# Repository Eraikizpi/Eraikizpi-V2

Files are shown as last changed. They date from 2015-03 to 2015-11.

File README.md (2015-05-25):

# Eraikizpi-V2
Open source dlp/sla 3d printer

En Mayo de 2014, el laboratorio ciudadano Hirikilabs (http://hirikilabs.tabakalera.eu/) impulsado por Tabakalera junto a DSS2016 abre una nueva convocatoria de proyectos abiertos (http://hirikilabs.tabakalera.eu/blog/2014/05/26/convocatoria-de-proyectos-abiertos/) donde presentamos el proyecto de una impresora 3d dlp con nombre en clave Eraikizpi. Hirikilabs acepta y apadrina nuestro proyecto, ademas nos costea el prototipo y nos permite utilizar sus instalaciones y maquinaría para el propósito del proyecto. Desde ese momento empezamos a trabajar en Eraikizpi.

Eraikizpi v2 es una impresora 3d stereolitográfica (SLA) que utiliza una resina fotosensible que es curada gracias a la luz ultra violeta que emite un proyector dlp (Digital Light Processing).

Teneis mas información en reprap
http://reprap.org/wiki/Eraikizpi/es

La licencia de la impresora Eraikizpi es CC BY-NC 4.0 (http://creativecommons.org/licenses/by-nc/4.0/)

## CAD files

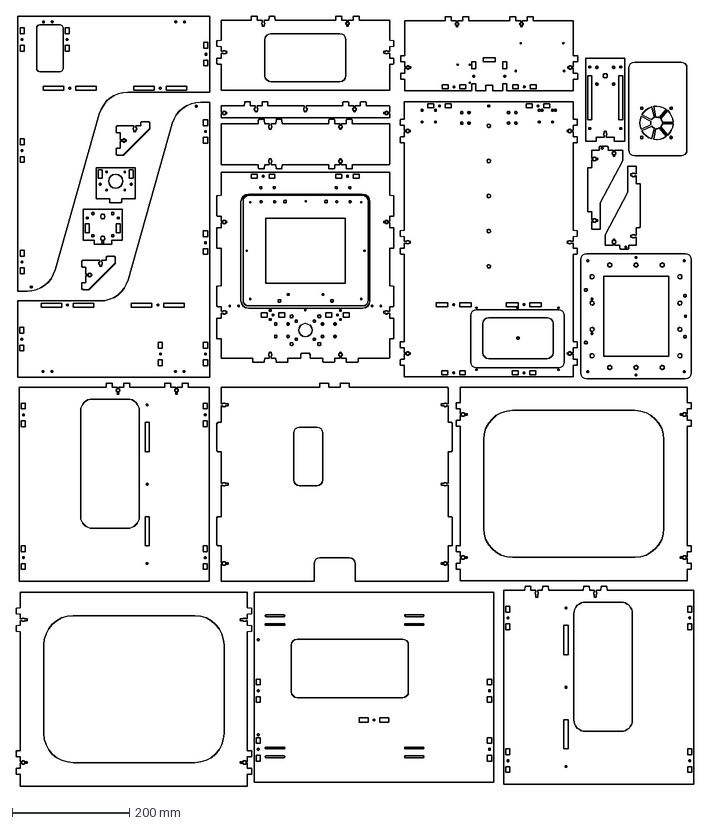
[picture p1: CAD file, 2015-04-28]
DXFs/DLP_V22_todo.DXF
1157.4 x 1315.2 mm

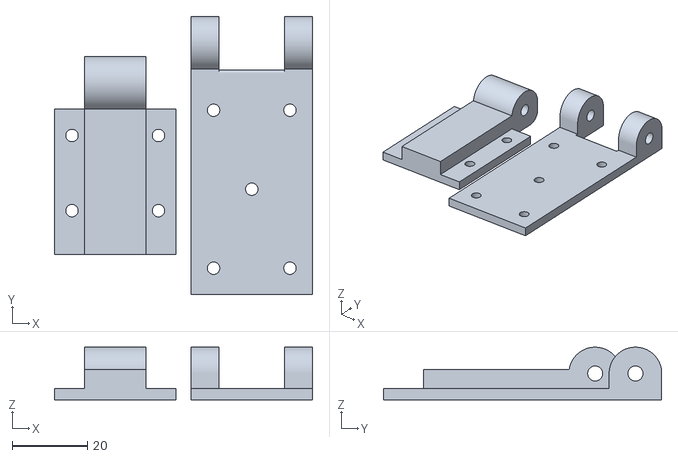
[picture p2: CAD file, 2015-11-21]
STLs/ERAKIZPI_V2_R2/ERKZP_V2_R2_02_bisagra_tapa_metacrilato.STL
68.6 x 73.9 x 14.0

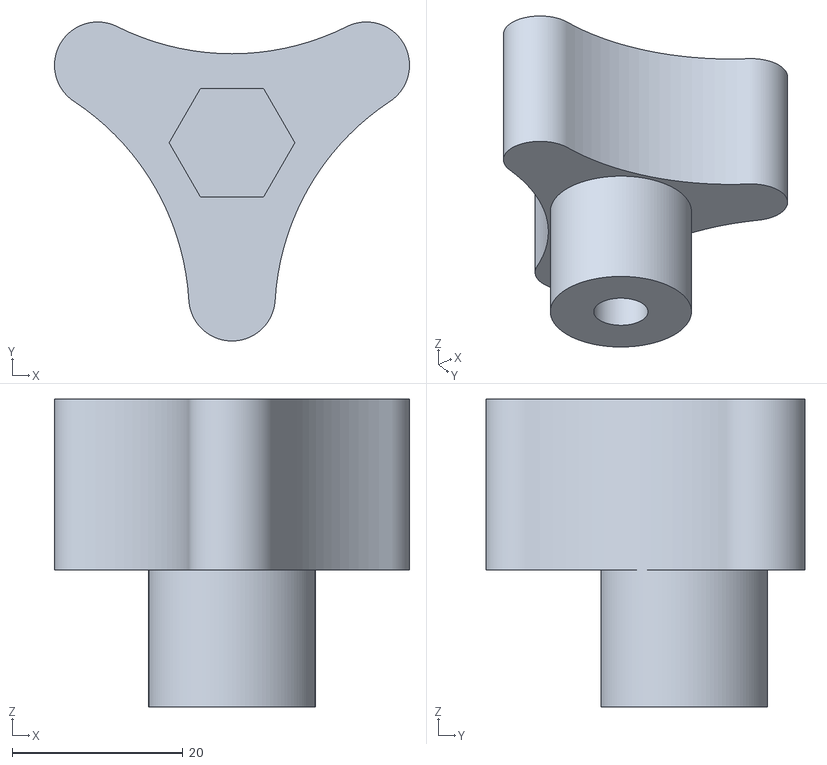
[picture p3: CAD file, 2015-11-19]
STLs/ERKZP_V2_R2_01_asa_bancada.STL
41.6 x 37.3 x 36.0

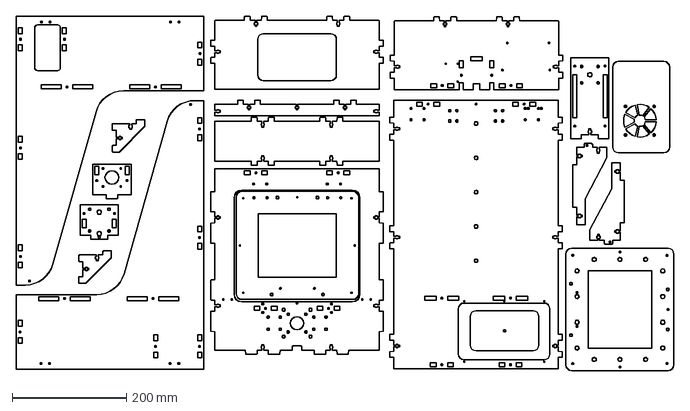
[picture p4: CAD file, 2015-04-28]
DXFs/DLP_V22_modulo_impresor.DXF
1150.8 x 619.8 mm

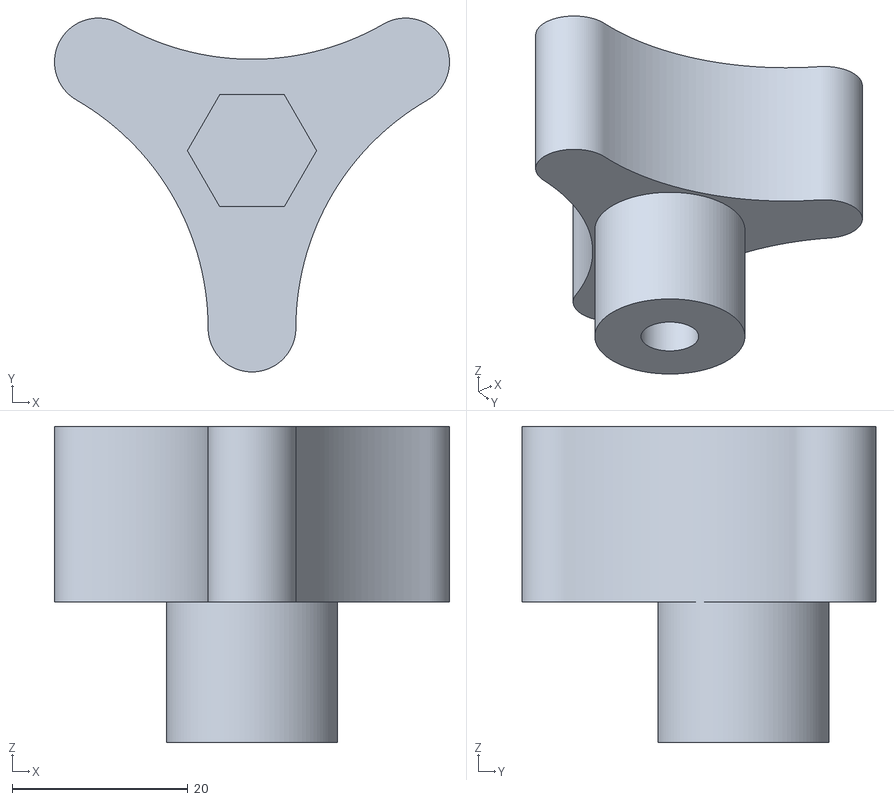
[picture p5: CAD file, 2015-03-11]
STLs/Bed_handle.STL
45.0 x 40.3 x 36.0

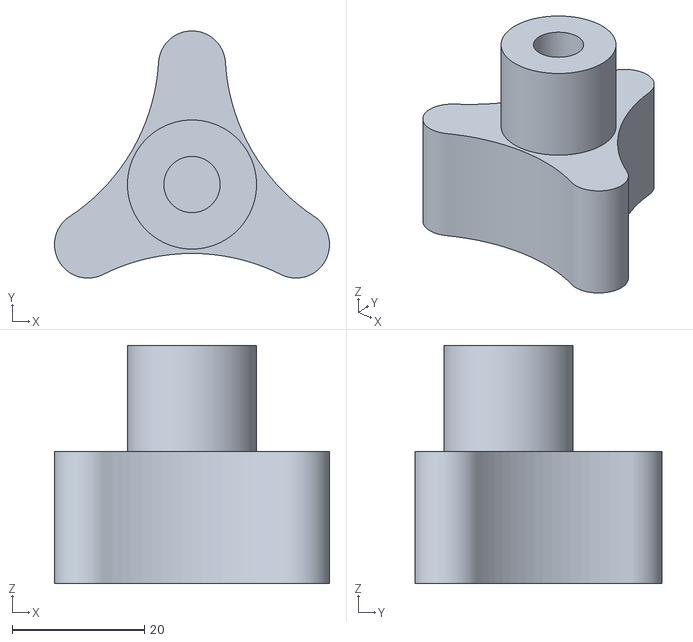
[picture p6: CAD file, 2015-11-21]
STLs/ERAKIZPI_V2_R2/ERKZP_V2_R2_01_asa_apriete_platf_constr.STL
41.6 x 37.3 x 36.0

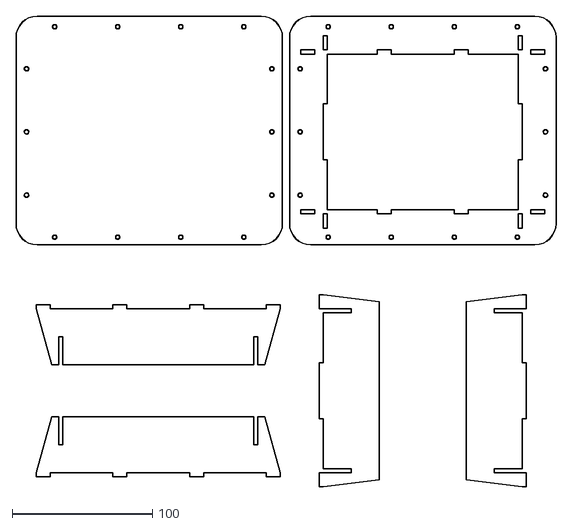
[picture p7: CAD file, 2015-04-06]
DXFs/pecera_fondo_metacrilato.dxf
385.1 x 335.5

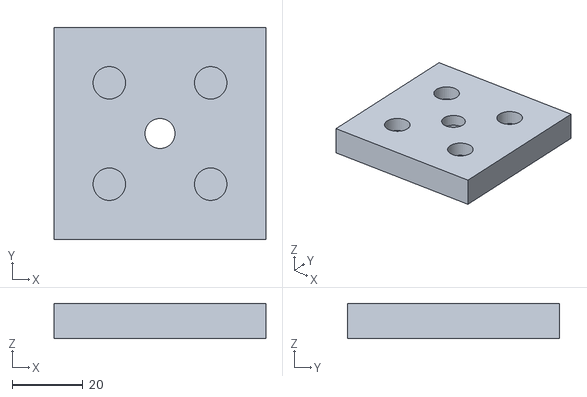
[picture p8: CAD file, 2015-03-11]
STLs/BP_1.STL
60.0 x 60.0 x 10.0

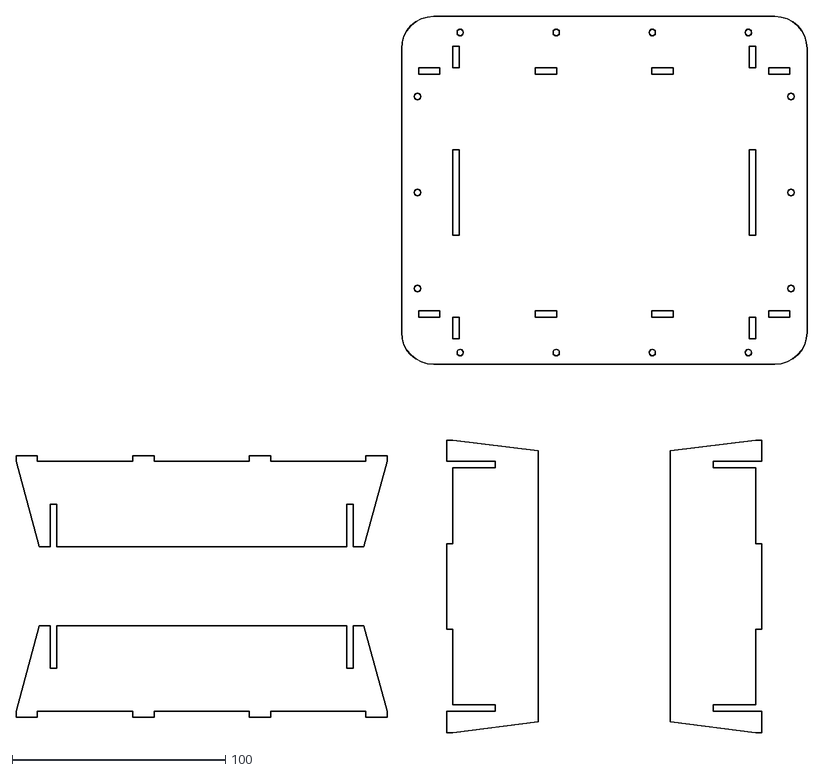
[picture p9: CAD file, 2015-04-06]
DXFs/pecera_base_silicona.dxf
370.7 x 335.5

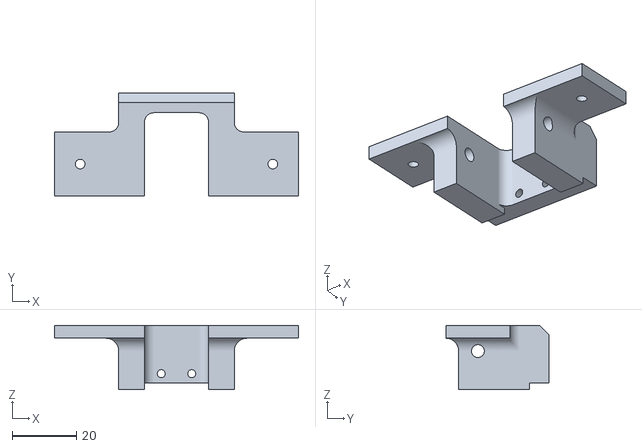
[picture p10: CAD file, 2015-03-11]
STLs/Tilt.STL
76.0 x 32.2 x 20.0

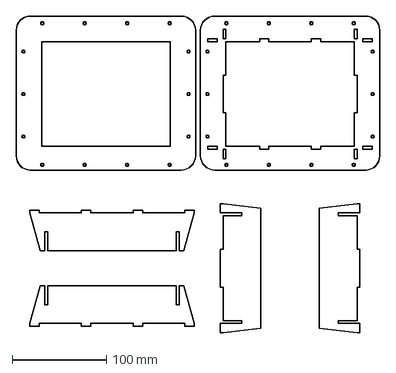
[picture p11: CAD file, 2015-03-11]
DXFs/pecera_base_vidrio.DXF
385.1 x 335.5 mm

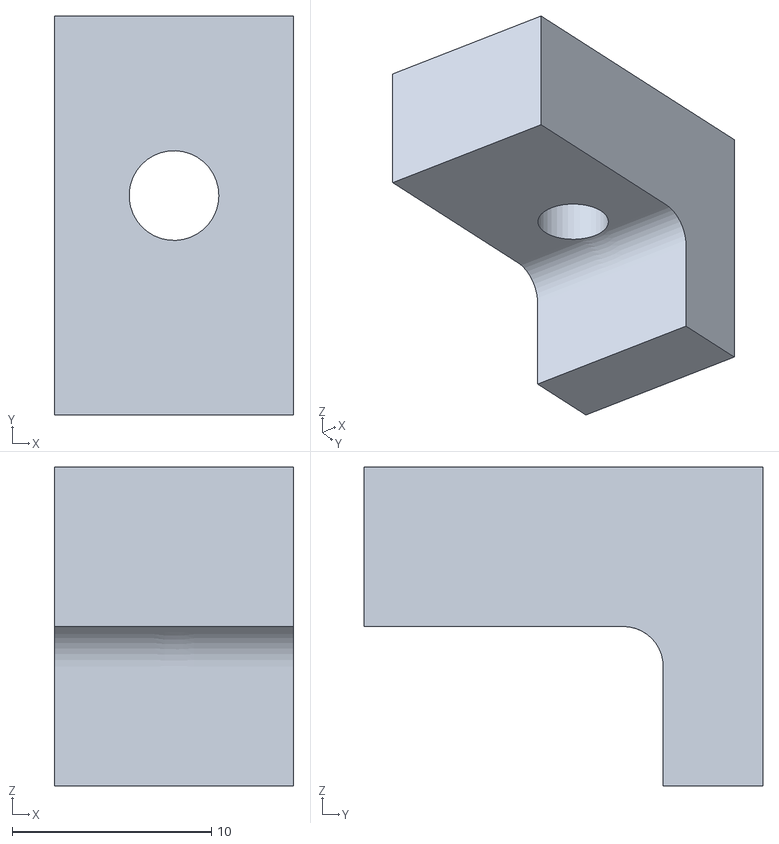
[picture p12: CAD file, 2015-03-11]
STLs/vat_stop.STL
12.0 x 20.0 x 16.0

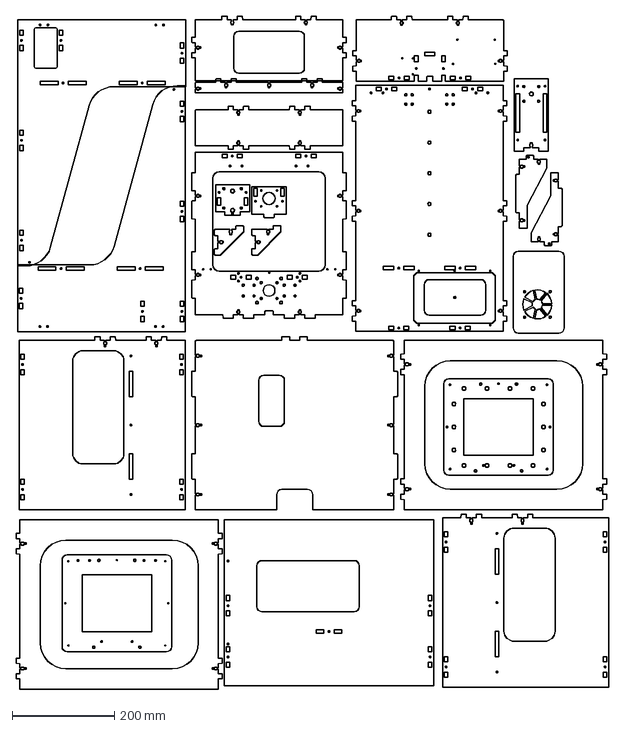
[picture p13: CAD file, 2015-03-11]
DXFs/DLP_V22.DXF
1157.4 x 1315.0 mm

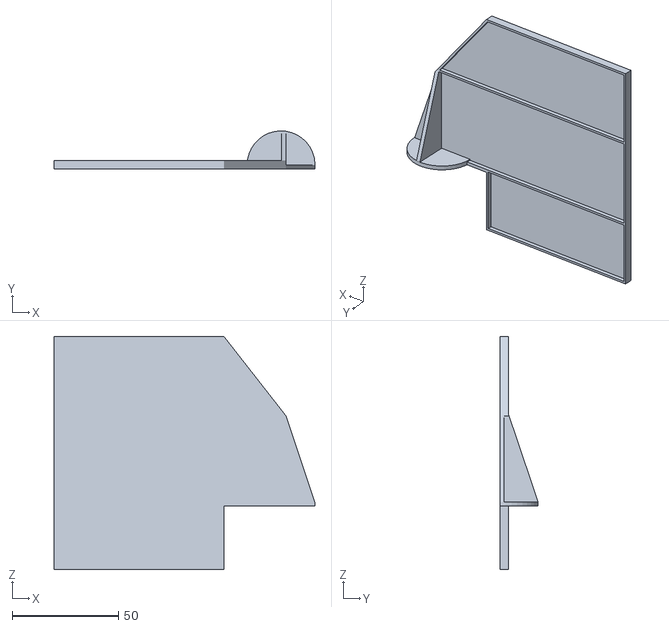
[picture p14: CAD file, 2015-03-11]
STLs/shooter_2.STL
123.0 x 18.0 x 110.0

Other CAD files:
STLs/Z_end_stop.STL
STLs/BP_flex_joint.STL
STLs/shooter_1.STL
STLs/Tank_base_stop.STL
STLs/Bisagra.STL
STLs/Tilt_nylon_screw.STL
STLs/Z_LM8UU_base.STL
STLs/Z_nylon_screw_insert_1.STL
STLs/Z_nylon_screw_insert_2.STL
STLs/passive_tilt_stopper.STL
STLs/shooter_22.STL

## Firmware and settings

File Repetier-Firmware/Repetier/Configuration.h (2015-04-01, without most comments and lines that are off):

#define CONFIGURATION_H
#define NUM_EXTRUDER 1
#define MOTHERBOARD 33
#include "pins.h"
#define FAN_BOARD_PIN -1
#define DRIVE_SYSTEM 0
#define XAXIS_STEPS_PER_MM 3400
#define YAXIS_STEPS_PER_MM 80
#define ZAXIS_STEPS_PER_MM 2560
#define EXTRUDER_FAN_COOL_TEMP 50
#define EXT0_X_OFFSET 0
#define EXT0_Y_OFFSET 0
#define EXT0_STEPS_PER_MM 150
#define EXT0_TEMPSENSOR_TYPE 8
#define EXT0_TEMPSENSOR_PIN TEMP_0_PIN
#define EXT0_HEATER_PIN HEATER_0_PIN
#define EXT0_STEP_PIN ORIG_E0_STEP_PIN
#define EXT0_DIR_PIN ORIG_E0_DIR_PIN
#define EXT0_INVERSE 1
#define EXT0_ENABLE_PIN E0_ENABLE_PIN
#define EXT0_ENABLE_ON 0
#define EXT0_MAX_FEEDRATE 50
#define EXT0_MAX_START_FEEDRATE 20
#define EXT0_MAX_ACCELERATION 5000
#define EXT0_HEAT_MANAGER 3
#define EXT0_WATCHPERIOD 1
#define EXT0_PID_INTEGRAL_DRIVE_MAX 230
#define EXT0_PID_INTEGRAL_DRIVE_MIN 40
#define EXT0_PID_P 7
#define EXT0_PID_I 2
#define EXT0_PID_D 40
#define EXT0_PID_MAX 255
#define EXT0_ADVANCE_K 0
#define EXT0_ADVANCE_L 0
#define EXT0_ADVANCE_BACKLASH_STEPS 0
#define EXT0_WAIT_RETRACT_TEMP 150
#define EXT0_WAIT_RETRACT_UNITS 0
#define EXT0_SELECT_COMMANDS ""
#define EXT0_DESELECT_COMMANDS ""
#define EXT0_EXTRUDER_COOLER_PIN -1
#define EXT0_EXTRUDER_COOLER_SPEED 255
#define RETRACT_DURING_HEATUP true
#define PID_CONTROL_RANGE 30
#define SKIP_M109_IF_WITHIN 5
#define SCALE_PID_TO_MAX 0
#define TEMP_HYSTERESIS 0
#define EXTRUDE_MAXLENGTH 160
#define NUM_TEMPS_USERTHERMISTOR0 0
#define USER_THERMISTORTABLE0 {}
#define NUM_TEMPS_USERTHERMISTOR1 0
#define USER_THERMISTORTABLE1 {}
#define NUM_TEMPS_USERTHERMISTOR2 0
#define USER_THERMISTORTABLE2 {}
#define GENERIC_THERM_VREF 5
#define GENERIC_THERM_NUM_ENTRIES 33
#define HEATER_PWM_SPEED 0
#define HAVE_HEATED_BED 1
#define HEATED_BED_MAX_TEMP 120
#define SKIP_M190_IF_WITHIN 3
#define HEATED_BED_SENSOR_TYPE 8
#define HEATED_BED_SENSOR_PIN TEMP_2_PIN
#define HEATED_BED_HEATER_PIN HEATER_1_PIN
#define HEATED_BED_SET_INTERVAL 5000
#define HEATED_BED_HEAT_MANAGER 0
#define HEATED_BED_PID_INTEGRAL_DRIVE_MAX 255
#define HEATED_BED_PID_INTEGRAL_DRIVE_MIN 80
#define HEATED_BED_PID_PGAIN   196
#define HEATED_BED_PID_IGAIN   33
#define HEATED_BED_PID_DGAIN 290
#define HEATED_BED_PID_MAX 255
#define MIN_EXTRUDER_TEMP 150
#define MAXTEMP 275
#define MIN_DEFECT_TEMPERATURE -10
#define MAX_DEFECT_TEMPERATURE 290
#define ENDSTOP_PULLUP_X_MIN true
#define ENDSTOP_X_MIN_INVERTING false
#define MIN_HARDWARE_ENDSTOP_X true
#define ENDSTOP_PULLUP_Y_MIN true
#define ENDSTOP_Y_MIN_INVERTING false
#define MIN_HARDWARE_ENDSTOP_Y true
#define ENDSTOP_PULLUP_Z_MIN true
#define ENDSTOP_Z_MIN_INVERTING false
#define MIN_HARDWARE_ENDSTOP_Z true
#define ENDSTOP_PULLUP_X_MAX true
#define ENDSTOP_X_MAX_INVERTING false
#define MAX_HARDWARE_ENDSTOP_X false
#define ENDSTOP_PULLUP_Y_MAX true
#define ENDSTOP_Y_MAX_INVERTING false
#define MAX_HARDWARE_ENDSTOP_Y false
#define ENDSTOP_PULLUP_Z_MAX true
#define ENDSTOP_Z_MAX_INVERTING false
#define MAX_HARDWARE_ENDSTOP_Z false
#define max_software_endstop_r true
#define min_software_endstop_x false
#define min_software_endstop_y false
#define min_software_endstop_z false
#define max_software_endstop_x true
#define max_software_endstop_y true
#define max_software_endstop_z true
#define ENDSTOP_X_BACK_MOVE 5
#define ENDSTOP_Y_BACK_MOVE 5
#define ENDSTOP_Z_BACK_MOVE 2
#define ENDSTOP_X_RETEST_REDUCTION_FACTOR 3
#define ENDSTOP_Y_RETEST_REDUCTION_FACTOR 3
#define ENDSTOP_Z_RETEST_REDUCTION_FACTOR 3
#define ENDSTOP_X_BACK_ON_HOME 0
#define ENDSTOP_Y_BACK_ON_HOME 1
#define ENDSTOP_Z_BACK_ON_HOME 0
#define ALWAYS_CHECK_ENDSTOPS 0
#define X_ENABLE_ON 0
#define Y_ENABLE_ON 0
#define Z_ENABLE_ON 0
#define DISABLE_X 0
#define DISABLE_Y 0
#define DISABLE_Z 0
#define DISABLE_E 0
#define INVERT_X_DIR 0
#define INVERT_Y_DIR 0
#define INVERT_Z_DIR 0
#define X_HOME_DIR -1
#define Y_HOME_DIR -1
#define Z_HOME_DIR -1
#define X_MAX_LENGTH 200
#define Y_MAX_LENGTH 200
#define Z_MAX_LENGTH 200
#define X_MIN_POS 0
#define Y_MIN_POS 0
#define Z_MIN_POS 0
#define FEATURE_BABYSTEPPING 1
#define BABYSTEP_MULTIPLICATOR 1
#define DELTA_SEGMENTS_PER_SECOND_PRINT 180 // Move accurate setting for print moves
#define DELTA_SEGMENTS_PER_SECOND_MOVE 70 // Less accurate setting for other moves
#define DELTA_HOME_ON_POWER 0
#define MAX_DELTA_SEGMENTS_PER_LINE 24
#define STEPPER_INACTIVE_TIME 60L
#define MAX_INACTIVE_TIME 0L
#define MAX_FEEDRATE_X 2
#define MAX_FEEDRATE_Y 200
#define MAX_FEEDRATE_Z 2
#define HOMING_FEEDRATE_X 2
#define HOMING_FEEDRATE_Y 40
#define HOMING_FEEDRATE_Z 2
#define HOMING_ORDER HOME_ORDER_XYZ
#define ENABLE_BACKLASH_COMPENSATION 0
#define X_BACKLASH 0
#define Y_BACKLASH 0
#define Z_BACKLASH 0
#define RAMP_ACCELERATION 1
#define STEPPER_HIGH_DELAY 0
#define STEP_DOUBLER_FREQUENCY 12000
#define ALLOW_QUADSTEPPING 1
#define DOUBLE_STEP_DELAY 1 // time in microseconds
#define MAX_HALFSTEP_INTERVAL 1999
#define MAX_ACCELERATION_UNITS_PER_SQ_SECOND_X 100
#define MAX_ACCELERATION_UNITS_PER_SQ_SECOND_Y 1000
#define MAX_ACCELERATION_UNITS_PER_SQ_SECOND_Z 100
#define MAX_TRAVEL_ACCELERATION_UNITS_PER_SQ_SECOND_X 100
#define MAX_TRAVEL_ACCELERATION_UNITS_PER_SQ_SECOND_Y 1000
#define MAX_TRAVEL_ACCELERATION_UNITS_PER_SQ_SECOND_Z 100
#define MAX_JERK 20
#define MAX_ZJERK 0.3
#define MOVE_CACHE_SIZE 16
#define MOVE_CACHE_LOW 10
#define LOW_TICKS_PER_MOVE 250000
#define FEATURE_TWO_XSTEPPER 0
#define X2_STEP_PIN   ORIG_E1_STEP_PIN
#define X2_DIR_PIN    ORIG_E1_DIR_PIN
#define X2_ENABLE_PIN E1_ENABLE_PIN
#define FEATURE_TWO_YSTEPPER 0
#define Y2_STEP_PIN   ORIG_E1_STEP_PIN
#define Y2_DIR_PIN    ORIG_E1_DIR_PIN
#define Y2_ENABLE_PIN E1_ENABLE_PIN
#define FEATURE_TWO_ZSTEPPER 0
#define Z2_STEP_PIN   ORIG_E1_STEP_PIN
#define Z2_DIR_PIN    ORIG_E1_DIR_PIN
#define Z2_ENABLE_PIN E1_ENABLE_PIN
#define FEATURE_DITTO_PRINTING 0
#define BAUDRATE 250000
#define ENABLE_POWER_ON_STARTUP
#define POWER_INVERTING 0
#define KILL_METHOD 1
#define GCODE_BUFFER_SIZE 2
#define ACK_WITH_LINENUMBER
#define WAITING_IDENTIFIER "wait"
#define ECHO_ON_EXECUTE
#define EEPROM_MODE 1
#define FEATURE_SERVO 1
#define SERVO0_PIN 11
#define SERVO1_PIN 6
#define SERVO2_PIN 5
#define SERVO3_PIN 4
#define FEATURE_WATCHDOG 0
#define FEATURE_Z_PROBE 0
#define Z_PROBE_BED_DISTANCE 10
#define Z_PROBE_PIN -1
#define Z_PROBE_PULLUP 0
#define Z_PROBE_ON_HIGH 0
#define Z_PROBE_X_OFFSET 0
#define Z_PROBE_Y_OFFSET 0
#define Z_PROBE_WAIT_BEFORE_TEST 0
#define Z_PROBE_SPEED 2
#define Z_PROBE_XY_SPEED 150
#define Z_PROBE_SWITCHING_DISTANCE 1
#define Z_PROBE_REPETITIONS 1
#define Z_PROBE_HEIGHT 40
#define Z_PROBE_START_SCRIPT ""
#define Z_PROBE_FINISHED_SCRIPT ""
#define FEATURE_AUTOLEVEL 1
#define Z_PROBE_X1 20
#define Z_PROBE_Y1 20
#define Z_PROBE_X2 160
#define Z_PROBE_Y2 20
#define Z_PROBE_X3 100
#define Z_PROBE_Y3 160
#define SDSUPPORT 0
#define SDCARDDETECT -1
#define SDCARDDETECTINVERTED 0
#define SD_EXTENDED_DIR 1
#define ARC_SUPPORT 1
#define FEATURE_MEMORY_POSITION 1
#define FEATURE_CHECKSUM_FORCED 0
#define FEATURE_FAN_CONTROL 1
#define FEATURE_CONTROLLER 0
#define UI_LANGUAGE 0
#define UI_PRINTER_NAME "RepRap"
#define UI_PRINTER_COMPANY "Home made"
#define UI_PAGES_DURATION 4000
#define UI_ANIMATION 1
#define UI_SPEEDDEPENDENT_POSITIONING 0
#define UI_DISABLE_AUTO_PAGESWITCH 1
#define UI_AUTORETURN_TO_MENU_AFTER 30000
#define FEATURE_UI_KEYS 0
#define UI_ENCODER_SPEED 1
#define UI_KEY_BOUNCETIME 10
#define UI_KEY_FIRST_REPEAT 500
#define UI_KEY_REDUCE_REPEAT 50
#define UI_KEY_MIN_REPEAT 50
#define FEATURE_BEEPER 0
#define CASE_LIGHTS_PIN -1
#define CASE_LIGHT_DEFAULT_ON 1
#define UI_START_SCREEN_DELAY 1000
#define BEEPER_SHORT_SEQUENCE 2,2
#define BEEPER_LONG_SEQUENCE 8,8
#define UI_SET_PRESET_HEATED_BED_TEMP_PLA 60
#define UI_SET_PRESET_EXTRUDER_TEMP_PLA   190
#define UI_SET_PRESET_HEATED_BED_TEMP_ABS 110
#define UI_SET_PRESET_EXTRUDER_TEMP_ABS   240
#define UI_SET_MIN_HEATED_BED_TEMP  30
#define UI_SET_MAX_HEATED_BED_TEMP 120
#define UI_SET_MIN_EXTRUDER_TEMP   170
#define UI_SET_MAX_EXTRUDER_TEMP   260
#define UI_SET_EXTRUDER_FEEDRATE 2
#define UI_SET_EXTRUDER_RETRACT_DISTANCE 3

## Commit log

2015-03-11 añadidos directorios stl y dxf
    [BP_1.STL, BP_flex_joint.STL, Bed_handle.STL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]
2015-04-01 Firmware para Eraikizpi
    El firmware que lleva Eriakizpi lo puedes abrir con el repetier firmare
    en
    http://www.repetier.com/firmware/v092/index.html
    no tienes mas que seleccionar el fichero configuration.h y subirlo para
    ver las configuraciones que lleva la impresora dlp
    [Configuration.h, Configuration_aurrekoa.h]
2015-04-06 añadidos mas tipos de peceras según desmoldeante
    [pecera_base_silicona.dxf, pecera_base_vidrio.DXF, pecera_fondo_metacrilato.dxf]
2015-04-28 nueva versión de plano dxf subida
    [DLP_V22_modulo_impresor.DXF, DLP_V22_todo.DXF]
2015-11-19 construction platform tightening handle
    outer diameter modification
    [ERKZP_V2_R2_01_asa_bancada.STL]
2015-11-21 Construction platform tightening handle
    Outer diameter modified
    Insert a M8 nut inside
    [ERKZP_V2_R2_01_asa_apriete_platf_constr.STL]
2015-11-21 Methacrylate cover hinge
    The .stl contains two pieces which can be joined with a M4 35mm long
    screw or dowel pin
    You can print them together or separated
    [ERKZP_V2_R2_02_bisagra_tapa_metacrilato.STL]
2015-11-21 Resin vat for 0.5mm thick elastic silicon sheet
    The .stl contains 4 pieces:
    1. main vat
    2. thightening ring
    3. vat holder
    4. plate for blind window (optional)
    You will need to split it into parts with CURA software for 3D printing.
    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

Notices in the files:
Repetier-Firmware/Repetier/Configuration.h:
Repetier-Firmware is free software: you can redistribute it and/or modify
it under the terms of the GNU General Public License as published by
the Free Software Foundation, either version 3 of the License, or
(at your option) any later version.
